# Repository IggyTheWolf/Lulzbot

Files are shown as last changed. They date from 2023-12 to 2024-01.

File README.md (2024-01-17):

# Installing Klipper

> [!CAUTION]
> Do this at your own risk!

> [!IMPORTANT]
> This is still a work in progress and incomplete. 

## Install Raspberry Pi OS (lite)

1. [Download the Pi Imager](https://www.raspberrypi.com/software/)
1. Select `Choose OS -> Raspberry Pi OS (other)`
1. Select `Raspberry Pi OS Lite (32bit)`
1. Click `Edit Settings` under `Use OS customization`
1. Set Hostname, Set username and password (pi/raspberry are defaults), Set locale settings, and enable SSH under services.
1. Write to SD Card

## [Install KIAUH](https://github.com/dw-0/kiauh)

1. Open a terminal and ssh into your pi. `ssh username@hostname.local` Change the username and hostname to the ones you set above in step 5. 
1. `sudo apt-get update && sudo apt-get install git -y`
1. `cd ~ && git clone https://github.com/dw-0/kiauh.git`
1. `./kiauh/kiauh.sh`

## Install Klipper

1. Open a terminal and ssh into your pi. `ssh username@hostname.local`
1. `./kiauh/kiauh.sh`
1. Enter 1 for `1) [Install]`
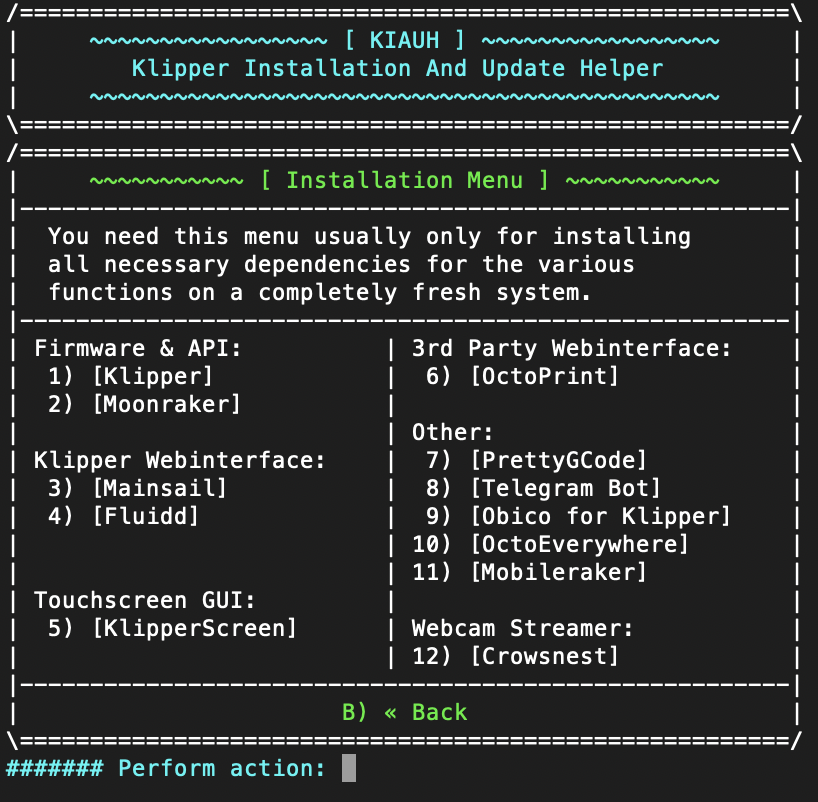
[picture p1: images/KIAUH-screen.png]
KIAUH Install Screen
1. 
   Install the following items in the this order (These 3 are required add more if you need them specifically)
   1. Klipper
   1. Moonraker
   1. Mainsail **OR** Fluidd (I will be using fluidd)

1. `sudo reboot` to reboot the pi

## [Building and Flashing your MCU](https://www.klipper3d.org/Installation.html#building-and-flashing-the-micro-controller)

1. Log in to Klipper via SSH
1. `cd ~/klipper/`
1. `make menuconfig`
1. Configure your settings according to the micro controller you are using.
   - Stock Rambo board (Taz6, Mini1, Mini2)
      - AVR atmega2560
   - Archim2 board (Taz6)
      - SAM3x8e
1. `make`
1. Plug in the printer via USB to pi and power it on.
1. `ls /dev/serial/by-id/*`
1. You printer should appear and look something like this. This is a unique ID and you'll need it later for the config file as well.
   - `/dev/serial/by-id/usb-1a86_USB2.0-Serial-if00-port0`
1. Now it's time to flash your board. Replace the ID with the one you got in the previous step.
   - `sudo service klipper stop`
   - `make flash FLASH_DEVICE=/dev/serial/by-id/usb-1a86_USB2.0-Serial-if00-port0`
   - `sudo service klipper start`
1. Reboot everything `sudo reboot`

## Adding and Configuring the printer.cfg

1. Open your broswer and head over to your printer.
1. On the left column select the `Configuation {...}` section
1. Locate your config file (there are some sample configs in the `configs` folder)

## Inital Test and Tuning

### Home and Initial Checks

From the Fluidd home screen, press the home button, and stand next to the power button just in case there are crashes. If the printer homes successfully, we are ready to move on.

### Initial Tunning

We are going to run some tests to make sure the printer is working correctly.

1. Check `rotaion distace`
1. Temp Tower
1. Flow Calibration
1. Pressure Advance Tuning
1. Calibration Cube Test Print
1. Input Shaper

## Input Shaper with a RP2040 and ADXL345

### Compile Firmware

1. Log into your printer via SSH.
1. `cd ~/klipper/`
1. `make menuconfig`
1. pic of selection
1. `Q` then `Y` to save
1. `make`

### Flash Firmware

1. Connect the Pi Pico (RP2040) holding down the `BOOTSEL` button
1. Given no other mass storage devices are existing, the Pico should register as block device `/dev/sda`
1. Mount the block device and copy the Klipper firmware file to it
	- `sudo mount /dev/sda1 /mnt`
	- `sudo cp out/klipper.uf2 /mnt`
	- `sudo umount /mnt`
1. After un-mounting, the Pico should automatically reboot with the new firmware.

### Configuring Klipper

1. Get the correct `serial` path with `ls /dev/serial/by-id/*`
1. It should look like this `/dev/serial/by-id/usb-Klipper_rp2040_45503571290DDAE8-if00`
1. Enter this value into the `adxl.cfg` file
1. Restart Klipper

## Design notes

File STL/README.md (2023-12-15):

# STL Files Pertaining to Luzbot Printers

These folders contain the files necessary to make some updates to your printers. Some are modifications to orignal Lulzbot files and others are original.

All files shared here are shared under the CC-BY SA 4.0 license; files with `[LB]`with attribution to Aleph Objects.

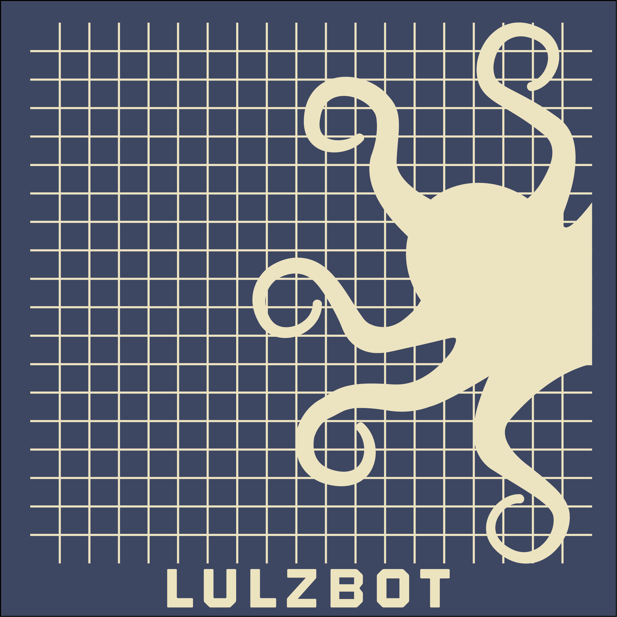
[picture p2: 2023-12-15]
Slicer Settings/Bed Images and Models/mini-bed.png

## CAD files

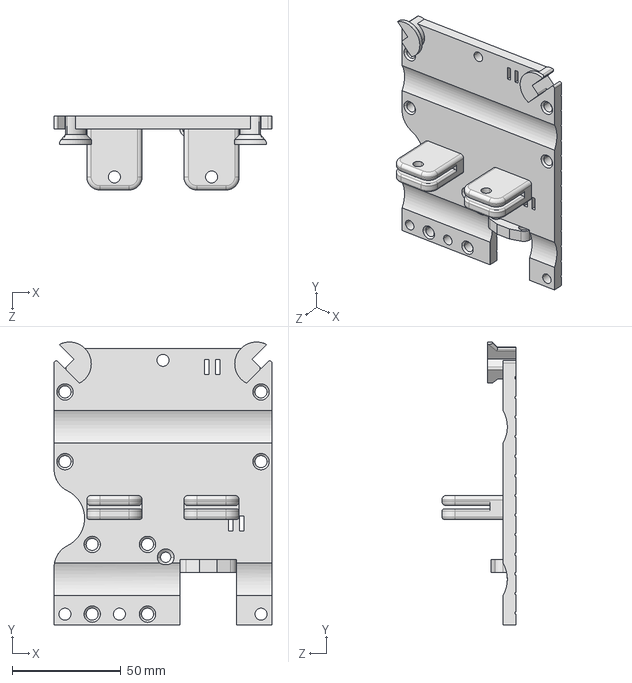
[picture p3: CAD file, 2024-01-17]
CAD/Taz6/taz6_x_carriage_bltouch.STEP
100.0 x 129.9 x 34.0 mm

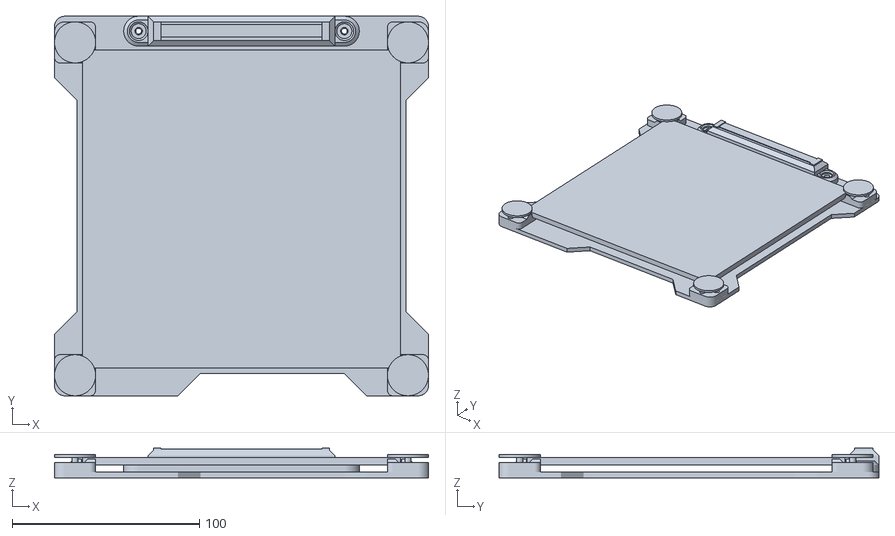
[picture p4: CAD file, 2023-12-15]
Slicer Settings/Bed Images and Models/lulzbot_mini[LB].stl
200.0 x 203.0 x 16.0

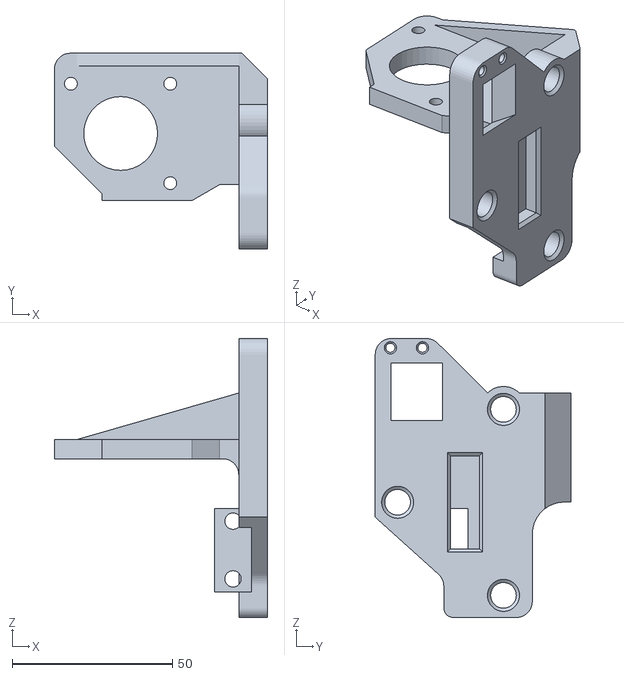
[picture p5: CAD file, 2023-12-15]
STL/Mini1/aero-mini-mount-BLTouch[LB].STL
66.5 x 61.0 x 87.0

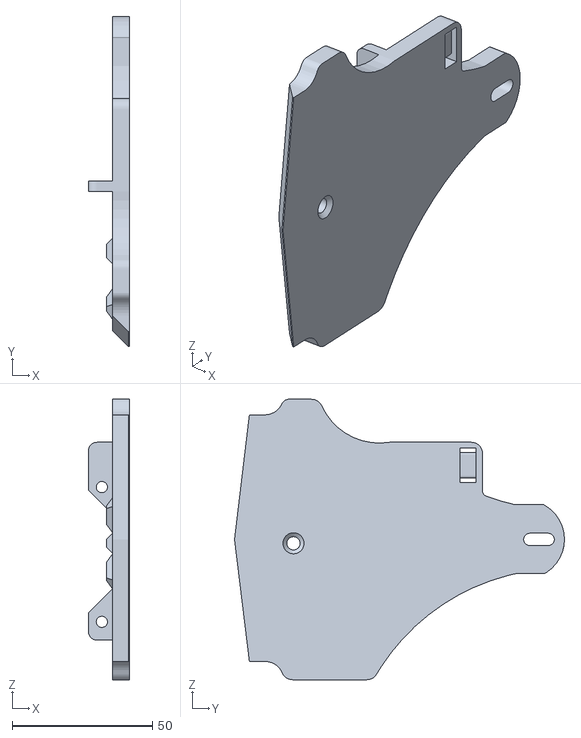
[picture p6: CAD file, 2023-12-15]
STL/Taz6/Taz6-Universal-Adapter-UPDATED[LB].STL
14.6 x 117.6 x 99.9

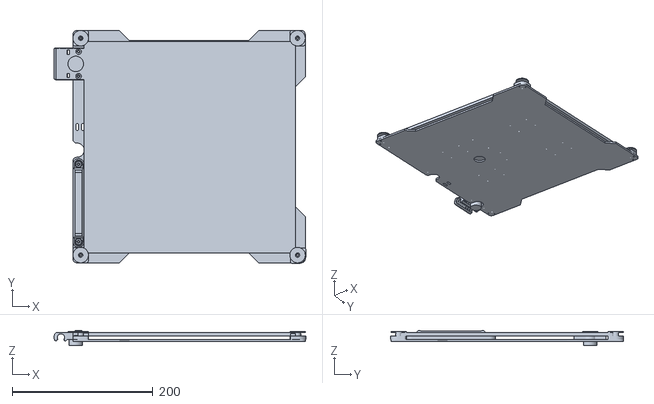
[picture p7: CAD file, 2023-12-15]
Slicer Settings/Bed Images and Models/lulzbot_taz6[LB].stl
357.9 x 331.0 x 21.8

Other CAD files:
STL/Taz6/X-Carriage-Stock-BLTouch[LB].STL

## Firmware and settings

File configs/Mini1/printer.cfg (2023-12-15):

#This file contains pin mappings for the Lulzbot Mini 1 using RAMBo Mini and SingleExtruder
#To use this config, the firmware should be compiled for the AVR atmega2560.

# See docs/Config_Reference.md for a description of parameters.

#-------------------------------------------------------------------------------------------------
# LULZBOT Mini 1 SingleExtruder (RAMBoMini)
# defines are copied from Marlin pins_MINIRAMBO.h
# pin conversion was found in fastio_1280.h
#-------------------------------------------------------------------------------------------------

[mcu]
##  Obtain definition by "ls -l /dev/serial/by-id/" then unplug to verify
##--------------------------------------------------------------------
#serial: /dev/ttyACM0 
serial: /dev/serial/by-id/usb-UltiMachine__ultimachine.com__RAMBo_858313036363517020E0-if00
restart_method: command
##--------------------------------------------------------------------

#[include adxl.cfg]

# [input_shaper]
# shaper_freq_x: 56.6
# shaper_type_x: 3hump_ei
# shaper_freq_y: 65.0
# shaper_type_y: 3hump_ei

[printer]
kinematics: cartesian
max_velocity: 300
max_accel: 3100
max_z_velocity: 7
max_z_accel: 500


#####################################################################
#   X/Y Stepper Settings
#####################################################################

[stepper_x]
#define X_STEP_PIN         37
step_pin: PC0
#define X_DIR_PIN          48
dir_pin: PL1
#define X_ENABLE_PIN       29
enable_pin: !PA7
# 1/100
microsteps: 16
rotation_distance: 32
#define X_MIN_PIN          12
endstop_pin: ^!PB6
position_endstop: -3
position_min: -3
position_max: 159
homing_speed: 50
homing_retract_dist: 2.0
second_homing_speed: 5

[stepper_y]
#define Y_STEP_PIN         36
step_pin: PC1
#define Y_DIR_PIN          49
dir_pin: !PL0
#define Y_ENABLE_PIN       28
enable_pin: !PA6
# 1/100
microsteps: 16
rotation_distance: 32
#define Y_MIN_PIN          11
endstop_pin: ^!PB5

#Uncomment for stock and Aerostruder heads
position_endstop: -7
position_min: -7
position_max: 173

# #Uncomment for toolheads with Universal Adapter
# position_endstop: -14
# position_min: -14
# position_max: 166


homing_speed: 50
homing_retract_dist: 2.0
second_homing_speed: 5

#####################################################################
#   Z Stepper Settings
#####################################################################

[stepper_z]
#define Z_STEP_PIN         35
step_pin: PC2
#define Z_DIR_PIN          47
dir_pin: PL2
#define Z_ENABLE_PIN       27
enable_pin: !PA5
# 1/1600
microsteps: 16
rotation_distance: 2
#define Z_MAX_PIN          23
endstop_pin: ^!PA1
# I have replaced the original nozzle with
# a hardened steel one that make the extruder
# 1-1.5mm longer, so this may be a little too low
#position_endstop: 161.5
position_max: 161.5
position_min: -2.0
homing_speed: 7
homing_retract_dist: 2.0
second_homing_speed: 2

#####################################################################
#   Extruder
#####################################################################

##-------------------------------------------------------------------
## settings for "Tilapia" Hexagon extruder (Mini standard)
##-------------------------------------------------------------------
# [extruder]
# #define E0_STEP_PIN        34
# step_pin: PC3
# #define E0_DIR_PIN         43
# dir_pin: !PL6
# #define E0_ENABLE_PIN      26
# enable_pin: !PA4
# # 1/833
# microsteps: 16
# rotation_distance: 3.842
# nozzle_diameter: 0.500
# filament_diameter: 2.850
# #define HEATER_0_PIN        3
# heater_pin: PE5
# #The Extruder uses 100K thermistor - ATC Semitec 104GT-2 (#5) and PID control
# sensor_type: ATC Semitec 104GT-2
# # I can't explain this from Marlin
# sensor_pin: PF0
# control: pid
# pid_Kp: 28.79
# pid_Ki: 1.91
# pid_Kd: 108.51
# min_temp: 0
# max_temp: 280
# min_extrude_temp: 160
# max_extrude_only_velocity: 500
# max_extrude_only_accel: 2000

#-------------------------------------------------------------------
# settings for "Angelfish" Aerostruder (E3D Titan Aero V6)
#-------------------------------------------------------------------
[extruder]
step_pin: PC3
dir_pin: !PL6
enable_pin: !PA4
microsteps: 16
#rotation_distance: 7.619
rotation_distance: 7.352
nozzle_diameter: 0.500
filament_diameter: 2.285
heater_pin: PE5
sensor_type: ATC Semitec 104NT-4-R025H42G
sensor_pin: PF0
#control: pid
#pid_Kp: 21.00
#pid_Ki: 1.78
#pid_Kd: 61.93
min_temp: 0
max_temp: 300
min_extrude_temp: 140
max_extrude_only_velocity: 500
max_extrude_only_accel: 2000
max_extrude_cross_section: 50.0
pressure_advance: 0.043

##-------------------------------------------------------------------
## settings for "KT-CP0181" H175 (E3D Hemera 1.75mm Revo)
##-------------------------------------------------------------------
# [extruder]
# step_pin: PC3
# dir_pin: !PL6
# enable_pin: !PA4
# microsteps: 16
# #rotation_distance: 7.65
# rotation_distance: 7.65
# nozzle_diameter: 0.600
# filament_diameter: 1.75
# heater_pin: PE5
# sensor_type: ATC Semitec 104NT-4-R025H42G
# sensor_pin: PF0
# #control: pid
# #pid_Kp: 21.00
# #pid_Ki: 1.78
# #pid_Kd: 61.93
# min_temp: 0
# max_temp: 300
# min_extrude_temp: 140
# max_extrude_only_velocity: 500
# max_extrude_only_accel: 2000
# max_extrude_cross_section: 50.0
# pressure_advance: 0.030


#####################################################################
#   Stepper Currents
#####################################################################

[output_pin stepper_xy_current]
#define MOTOR_CURRENT_PWM_XY_PIN 46
pin: PL3
pwm: True
scale: 2.0
cycle_time: .000030
hardware_pwm: True
static_value: 1.300

[output_pin stepper_z_current]
pin: PL4
pwm: True
scale: 2.0
cycle_time: .000030
hardware_pwm: True
static_value: 1.630

[output_pin stepper_e_current]
pin: PL5
pwm: True
scale: 2.0
cycle_time: .000030
hardware_pwm: True
static_value: 1.250

[static_digital_output stepper_config]
# Microstepping pins
#define X_MS1_PIN          40
#define X_MS2_PIN          41
#define Y_MS1_PIN          69
#define Y_MS2_PIN          39
#define Z_MS1_PIN          68
#define Z_MS2_PIN          67
#define E0_MS1_PIN         65
#define E0_MS2_PIN         66
pins:
    PG1, PG0,
    PK7, PG2,
    PK6, PK5,
    PK3, PK4

#####################################################################
#   Bed Heater
#####################################################################

[heater_bed]
#define HEATER_BED_PIN      4
heater_pin: PG5
# The Heater Bed uses Honeywell 100K 135-104LAG-J01 temp sensor (#7) and PID control
sensor_type: Honeywell 100K 135-104LAG-J01
# I can't explain this from Marlin
sensor_pin: PF2
#control: pid
#pid_Kp: 294.0
#pid_Ki: 65.0
#pid_Kd: 382.0
min_temp: 0
max_temp: 130

#####################################################################
#   Probe
#####################################################################

##-------------------------------------------------------------------
## Washer Probing
##-------------------------------------------------------------------
# [probe]
# #define Z_MIN_PROBE_PIN  10
# pin: ^!PB4
# # z_offset equals washer thickness ~= 1.377
# z_offset: 1.377
# speed: 5.0
# samples: 2
# sample_retract_dist: 1.0
# samples_result: average
# samples_tolerance: 0.200
# samples_tolerance_retries: 2

##-------------------------------------------------------------------
## BLTouch Probing
##-------------------------------------------------------------------
[bltouch]
sensor_pin: ^PB4
control_pin: PD1

##*************************************
##Uncomment for Lulzbot Aero Toolheads
x_offset: -15.0
y_offset: 24
##*************************************

##*************************************
##Uncomment for Hemera Toolheads
# x_offset: 0
# y_offset: 28.5
##*************************************

z_offset: 4.50
speed: 5.0
samples: 2
sample_retract_dist: 5.0
samples_result: average
samples_tolerance: 0.200
samples_tolerance_retries: 2


#####################################################################
#   Fan Control
#####################################################################

[fan]
#define FAN_PIN             8
pin: PH5

[heater_fan nozzle_cooling_fan]
#define FAN1_PIN            6
#pin: PH3
pin: PE4

[controller_fan controller_fan]
#define FAN2_PIN            PWM2
#pin: PE4
pin: PH3
kick_start_time: 0.5
heater: heater_bed
fan_speed: .75

#####################################################################
#   LED Control
#####################################################################

[static_digital_output yellow_led]
#define LED_PIN            13
pins: !PB7

#####################################################################
#   Homing  Routines
#####################################################################
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

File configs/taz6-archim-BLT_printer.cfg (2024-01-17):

# This config is for a Taz6 with Archim2 baord and SE Toolhead
# This file contains common pin mappings for Ultimachine Archim2
# boards. To use this config, the firmware should be compiled for the
# SAM3x8e.

# See docs/Config_Reference.md for a description of parameters.

[mcu]
##  Obtain definition by "ls -l /dev/serial/by-id/" then unplug to verify
##--------------------------------------------------------------------
serial: /dev/serial/by-id/...

[printer]
kinematics: cartesian
max_velocity: 300
max_accel: 9000
max_z_velocity: 3
max_z_accel: 100


#####################################################################
#   X/Y Stepper Settings
#####################################################################

[stepper_x]
step_pin: PC6
dir_pin: PC5
enable_pin: !PC9
microsteps: 16
rotation_distance: 32
endstop_pin: ^PD4
position_endstop: -20
position_min: -20
position_max: 300
homing_speed: 50

[tmc2130 stepper_x]
cs_pin: PC7
run_current: 0.75
sense_resistor: 0.120
diag1_pin: !PA4
spi_software_sclk_pin: PD2
spi_software_mosi_pin: PD3
spi_software_miso_pin: PD1

[stepper_y]
step_pin: PC12
dir_pin: !PC11
enable_pin: !PC14
microsteps: 16
rotation_distance: 32
endstop_pin: ^PD6
position_endstop: -20
position_min: -20
position_max: 306
homing_speed: 50

[tmc2130 stepper_y]
cs_pin: PC13
run_current: 0.75
sense_resistor: 0.120
diag1_pin: !PC15
spi_software_sclk_pin: PD2
spi_software_mosi_pin: PD3
spi_software_miso_pin: PD1

#####################################################################
#   Z Stepper Settings
#####################################################################

[stepper_z]
step_pin: PC17
dir_pin: PC16
enable_pin: !PC19
microsteps: 16
rotation_distance: 2
endstop_pin: probe:z_virtual_endstop
position_max: 250
position_min: -3
homing_speed: 2

[tmc2130 stepper_z]
cs_pin: PC18
run_current: 1.0
sense_resistor: 0.120
diag1_pin: PC4
spi_software_sclk_pin: PD2
spi_software_mosi_pin: PD3
spi_software_miso_pin: PD1

#####################################################################
#   Extruder
#####################################################################

##-------------------------------------------------------------------
## settings for "KT-CP0181" H175 (E3D Hemera 1.75mm Revo)
##-------------------------------------------------------------------
# [extruder]
# step_pin: PB10
# dir_pin: !PC10
# enable_pin: !PB22
# microsteps: 16
# rotation_distance: 7.619
# nozzle_diameter: 0.400
# filament_diameter: 1.75
# heater_pin: PC24
# sensor_type: ATC Semitec 104GT-2
# sensor_pin: PB19
# control: pid
# pid_Kp: 21.0
# pid_Ki: 1.78
# pid_Kd: 61.93
# min_temp: 0
# max_temp: 300
# min_extrude_temp: 140

# [tmc2130 extruder]
# cs_pin: PC20
# run_current: 0.678
# sense_resistor: 0.120
# diag1_pin: !PB23
# spi_software_sclk_pin: PD2
# spi_software_mosi_pin: PD3
# spi_software_miso_pin: PD1

#-------------------------------------------------------------------
# settings for "Angelfish" Aerostruder (E3D Titan Aero V6)
#-------------------------------------------------------------------
[extruder]
step_pin: PB10
dir_pin: !PC10
enable_pin: !PB22
microsteps: 16
rotation_distance: 7.242
nozzle_diameter: 0.500
filament_diameter: 2.85
heater_pin: PC24
sensor_type: ATC Semitec 104GT-2
sensor_pin: PB19
control: pid
pid_Kp: 21.0
pid_Ki: 1.78
pid_Kd: 61.93
min_temp: 0
max_temp: 300
min_extrude_temp: 140
max_extrude_only_velocity: 500
max_extrude_only_accel: 2000
max_extrude_cross_section: 50.0
max_extrude_only_distance: 140.0

[tmc2130 extruder]
cs_pin: PC20
run_current: 0.678
sense_resistor: 0.120
diag1_pin: !PB23
spi_software_sclk_pin: PD2
spi_software_mosi_pin: PD3
spi_software_miso_pin: PD1

#####################################################################
#   Bed Heater
#####################################################################

[heater_bed]
heater_pin: PC21
sensor_type: Honeywell 100K 135-104LAG-J01
sensor_pin: PB20
control: pid
pid_Kp: 162.0
pid_Ki: 17.0
pid_Kd: 378.0
min_temp: 0
max_temp: 130

#####################################################################
#   Probe
#####################################################################

[bltouch]
sensor_pin: PA7
#J7 Pin 1 - MIN ES3
control_pin: PB12
#GPIO Pin 20 - PB12_AD8
pin_move_time: 0.680
#   The amount of time (in seconds) to wait for the BLTouch pin to
#   move up or down. The default is 0.680 seconds.
stow_on_each_sample: False
probe_with_touch_mode: True
x_offset: -19.50
y_offset: 47.00
z_offset: 1.50
samples: 2
sample_retract_dist: 3.0
samples_result: average
samples_tolerance: 0.200
samples_tolerance_retries: 2

[bed_mesh]
speed: 200
horizontal_move_z: 10
mesh_min: 0,33
mesh_max: 270,270
fade_start: 0.6
fade_end: 10.0
probe_count: 5,5
algorithm: bicubic

[safe_z_home]
home_xy_position: 140,140 # Change coordinates to the center of your print bed
speed: 100
z_hop: 10                 # Move up 10mm

#####################################################################
#   Fan Control
#####################################################################

[fan]
pin: PC26

[heater_fan heatbreak_cooling_fan]
pin: PC25

#####################################################################
#   Displays
#####################################################################

[display]
lcd_type: st7920
cs_pin: EXP1_4
sclk_pin: EXP1_5
sid_pin: EXP1_3
encoder_pins: ^EXP2_5, ^EXP2_3
click_pin: ^!EXP1_2
menu_timeout: 5

########################################
# EXP1 / EXP2 (display) pins
########################################

[board_pins]
aliases:
    # EXP1 header
    EXP1_1=PA14, EXP1_3=PA15, EXP1_5=PA0,  EXP1_7=PA1, EXP1_9=<GND>,
    EXP1_2=PA13, EXP1_4=PA12, EXP1_6=PA16, EXP1_8=PC2, EXP1_10=<5V>,
    # EXP2 header
    EXP2_1=PA25, EXP2_3=PB27, EXP2_5=PA3,  EXP2_7=PB25,  EXP2_9=<GND>,
    EXP2_2=PA27, EXP2_4=PA29, EXP2_6=PA26, EXP2_8=<RST>, EXP2_10=<3.3V>
    # Pins EXP2_1, EXP2_6, EXP2_2 are also MISO, MOSI, SCK of bus "spi0"

# See the sample-lcd.cfg file for definitions of common LCD displays.

#####################################################################
#   Macros
#####################################################################

[include fluidd.cfg]

##### Enable object exclusion #####
[exclude_object]

[gcode_macro G29]
# Preform the ABL by running G29 in the start GCODE script
gcode:
    BED_MESH

[gcode_macro G32]
gcode:
    BED_MESH_CLEAR
    G28
    G0 X140 Y140 Z30 F3600

[gcode_macro MOVE_CENTER_BED]
gcode:
    G28                               ; Home Axis
    G0 X140 Y140 Z50  F6000           ; Move to center of bed

[gcode_macro G32]
gcode:
    BED_MESH_CLEAR
    G28
    G0 X140 Y140 Z30 F3600

[gcode_macro Z_OFFSET]
gcode:
	M140 S110 ;set bed to 110
	M104 S240 ;set extruder to 240
	G28
	BED_MESH_CLEAR
	G0 Y140 X140
	Z_ENDSTOP_CALIBRATE

[gcode_macro PRINT_START]
gcode:

    {% set BED = params.BED|default(69)|int %}
    {% set EXTRUDER = params.EXTRUDER|default(204)|int %}

    M117 Heating bed...
    M190 S{BED}             ; set final bed temperature and wait for it to be reached
    M104 S{EXTRUDER*0.80}   ; start preheating hotend to non-ooze temperature
    M117 Homing...
    G28
    M117 Calibrating mesh...
    BED_MESH_CALIBRATE

    #Purge Line Gcode
    G92 E0
    G90
    G0 X5 Y-5 F6000
    M117 Heating extruder...
    M109 S{EXTRUDER}            ; set final hotend temperature and wait for it 
    G1 E12.0 F3600              ; prime filament
    PURGE_LINE                  ; call purge line
    G1 Z10.0 F600           ; move the platform down 10mm
    G92 E0                  ; zero the extruded length again
    G1 F9000
    M117 Printing
   
[gcode_macro PRINT_END]
#   Use PRINT_END for the slicer ending script - please customise for your slicer of choice
gcode:
    # safe anti-stringing move coords
    {% set th = printer.toolhead %}
    {% set x_safe = th.position.x + 20 * (1 if th.axis_maximum.x - th.position.x > 20 else -1) %}
    {% set y_safe = th.position.y + 20 * (1 if th.axis_maximum.y - th.position.y > 20 else -1) %}
    {% set z_safe = [th.position.z + 2, th.axis_maximum.z]|min %}
    
    SAVE_GCODE_STATE NAME=STATE_PRINT_END
    
    M400                           ; wait for buffer to clear
    G92 E0                         ; zero the extruder
    G1 E-12.0 F3600                 ; retract filament
    
    TURN_OFF_HEATERS
    
    G90                                      ; absolute positioning
    G0 X{x_safe} Y{y_safe} Z{z_safe} F20000  ; move nozzle to remove stringing
    #G0 X{th.axis_maximum.x//2} Y{th.axis_maximum.y - 2} Z{th.axis_maximum.z - 2}F3600  ; park nozzle at rear
    G0 X{th.axis_maximum.x//2} Y{th.axis_maximum.y - 2} F3600  ; park nozzle at rear
    M107                                     ; turn off fan
    M117
    BED_MESH_CLEAR
    RESTORE_GCODE_STATE NAME=STATE_PRINT_END
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

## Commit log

2023-12-04 Add files via upload
    Added STL files to make adding a BLTouch to a Taz6 and Mini 1 easy and to match the config files.
    [Taz6-Universal-Adapter-UPDATED[LB].STL, X-Carriage-Stock-BLTouch[LB].STL, aero-mini-mount-BLTouch[LB].STL]
2023-12-11 added config files for printers
    The taz configs are not tested. Adding these for reference.
    [Taz6-Archim2-hemera-bltouch-printer.cfg, Taz6-Archim2-printer.cfg, Taz6-stock-config.cfg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]
2023-12-15 synced with current
    [Taz6-Archim2-hemera-bltouch-printer.cfg, Taz6-Archim2-printer.cfg, Taz6-Universal-Adapter-UPDATED[LB].STL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]
2024-01-17 updated files
    [Taz6-Archim2-hemera-bltouch-printer.cfg, taz6-archim-BLT_printer.cfg, taz6_x_carriage_bltouch.STEP]
